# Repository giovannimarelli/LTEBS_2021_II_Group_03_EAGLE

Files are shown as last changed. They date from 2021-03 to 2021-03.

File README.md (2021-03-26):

# LTEBS_2021_II_Group_03_EAGLE
Laboratorio di Tecnologie Elettroniche e Biosensori S2021-II Group 03 EAGLE

In the Library folder, inside the Group_03_Library file we have inserted the two additional devices we were required to make and the microcontroller, for which we modified the footprint (setting line width of the silkscreen according to the manufacturer's specs); other devices referred to Sparkfun Library were not included, supposing to be in your possess. 
For what regards the TMUX device, we built the UQFN package, as specified by the description table inside the PDF, even if inside the provided schematic pins followed the 
TSSOP pattern. The same applies for the CY8CKIT059-TARGET: the table said to pick this, whereas inside the schematic the one used was the CY8CKIT059-TARGET_3: as before, we 
followed the table specs.

Inside the .brd file, Power Jack device looks like it exits the pcb: we intentionally placed it there folowing some examples online. 

All traces are of 10 mils, as you asked in the assignment document. However, due to the small dimension of the MUX, the design rules generated errors due to the clearance of the traces connecting the pads to the other pins. To overcome this problem, we decided to convert the width of all the traces connected to the MUX to 8 mils.

We added Silkscreen references for all SMD components, respecting manufacturer's rules of clearance and distance from the pads (8 mil from any exposed copper part).

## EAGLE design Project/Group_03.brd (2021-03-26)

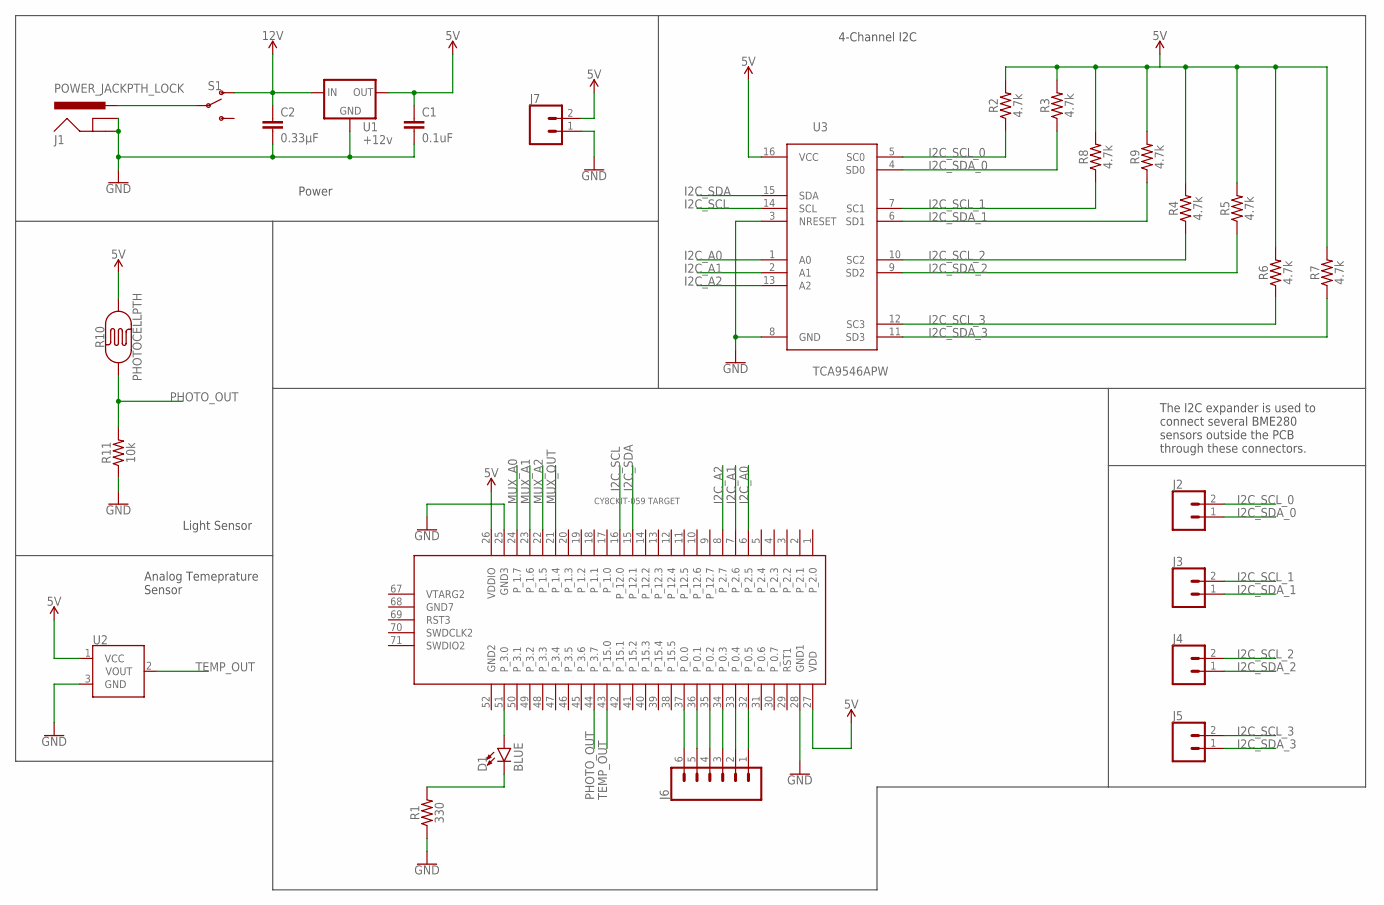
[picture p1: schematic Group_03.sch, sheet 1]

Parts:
C1: 0.1uF; CAP-PTH-SMALL-KIT
C2: 0.33µF; 0805
D1: BLUE; LED-1206
J1: POWER_JACKPTH_LOCK; POWER_JACK_PTH_LOCK
J2, J3, J4, J5, J7: CONN_02; 1X02
J6: CONN_06LOCK; 1X06_LOCK
R1: 330; AXIAL-0.3
R2, R3, R4, R5, R6, R7, R8, R9: 4.7k; 0603
R10: PHOTOCELLPTH; PHOTOCELL
R11: 10k; 0603
S1: SWITCH-SPDT-PTH-11.6X4.0MM; SWITCH_SPDT_PTH_11.6X4.0MM
U1: +12v; TO-252
U2: TMP36GT9; TO-92
U3: TCA9546APW; TSSOP16
U$1: CY8CKIT-059_TARGET

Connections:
5V: C1.1, J7.2, R2.2, R3.2, R4.2, R5.2, R6.2, R7.2, R8.2, R9.2, R10.2, U1.2 (OUT), U2.1 (VCC), U3.16 (VCC), U$1.26 (VDDIO), U$1.27 (VDD); also elsewhere on the board
12V: C2.1, S1.1 (O), U1.1 (IN)
GND: C1.2, C2.2, J1.GND, J1.GNDBREAK, J7.1, R1.P$1 (1), R11.1, U1.3 (GND), U2.3 (GND), U3.3 (NRESET), U3.8 (GND), U$1.25 (GND3), U$1.28 (GND1); also elsewhere on the board
I2C_A0: U3.1 (A0), U$1.6 (P_2.5)
I2C_A1: U3.2 (A1), U$1.7 (P_2.6)
I2C_A2: U3.13 (A2), U$1.8 (P_2.7)
I2C_SCL: U3.14 (SCL), U$1.16 (P_12.0)
I2C_SCL_0: J2.2, R2.1, U3.5 (SC0)
I2C_SCL_1: J3.2, R8.1, U3.7 (SC1)
I2C_SCL_2: J4.2, R4.1, U3.10 (SC2)
I2C_SCL_3: J5.2, R6.1, U3.12 (SC3)
I2C_SDA: U3.15 (SDA), U$1.15 (P_12.1)
I2C_SDA_0: J2.1, R3.1, U3.4 (SD0)
I2C_SDA_1: J3.1, R9.1, U3.6 (SD1)
I2C_SDA_2: J4.1, R5.1, U3.9 (SD2)
I2C_SDA_3: J5.1, R7.1, U3.11 (SD3)
MUX_A0: U$1.24 (P_1.7); also elsewhere on the board
MUX_A1: U$1.23 (P_1.6); also elsewhere on the board
MUX_A2: U$1.22 (P_1.5); also elsewhere on the board
MUX_OUT: U$1.21 (P_1.4); also elsewhere on the board
unnamed: J1.PWR, S1.2
unnamed: J6.1, U$1.32 (P_0.5)
unnamed: J6.2, U$1.33 (P_0.4)
unnamed: J6.3, U$1.34 (P_0.3)
unnamed: J6.4, U$1.35 (P_0.2)
unnamed: J6.5, U$1.36 (P_0.1)
unnamed: J6.6, U$1.37 (P_0.0)
unnamed: D1.A, U$1.51 (P_3.0)
unnamed: D1.C, R1.P$2 (2)
PHOTO_OUT: R10.1, R11.2, U$1.44 (P_3.7)
TEMP_OUT: U2.2 (VOUT), U$1.43 (P_15.0)

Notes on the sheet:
The I2C expander is used to connect several BME280 sensors outside the PCB through these connectors.
Analog Temeprature Sensor
Light Sensor
Power
4-Channel I2C

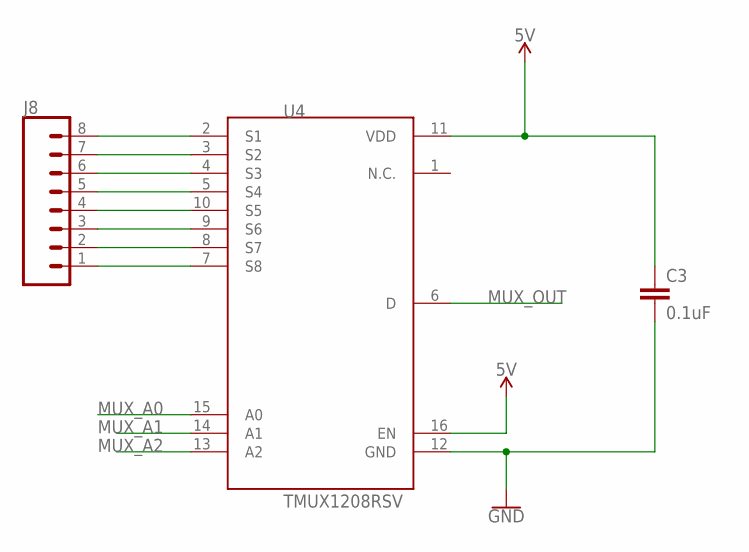
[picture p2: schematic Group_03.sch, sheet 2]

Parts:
C3: 0.1uF; CAP-PTH-SMALL-KIT
J8: CONN_08LOCK; 1X08_LOCK
U4: TMUX1208RSV; QFN16

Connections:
5V: C3.1, U4.11 (VDD), U4.16 (EN); also elsewhere on the board
GND: C3.2, U4.12 (GND); also elsewhere on the board
MUX_A0: U4.15 (A0); also elsewhere on the board
MUX_A1: U4.14 (A1); also elsewhere on the board
MUX_A2: U4.13 (A2); also elsewhere on the board
MUX_OUT: U4.6 (D); also elsewhere on the board
unnamed: J8.8, U4.2 (S1)
unnamed: J8.7, U4.3 (S2)
unnamed: J8.6, U4.4 (S3)
unnamed: J8.5, U4.5 (S4)
unnamed: J8.4, U4.10 (S5)
unnamed: J8.3, U4.9 (S6)
unnamed: J8.2, U4.8 (S7)
unnamed: J8.1, U4.7 (S8)

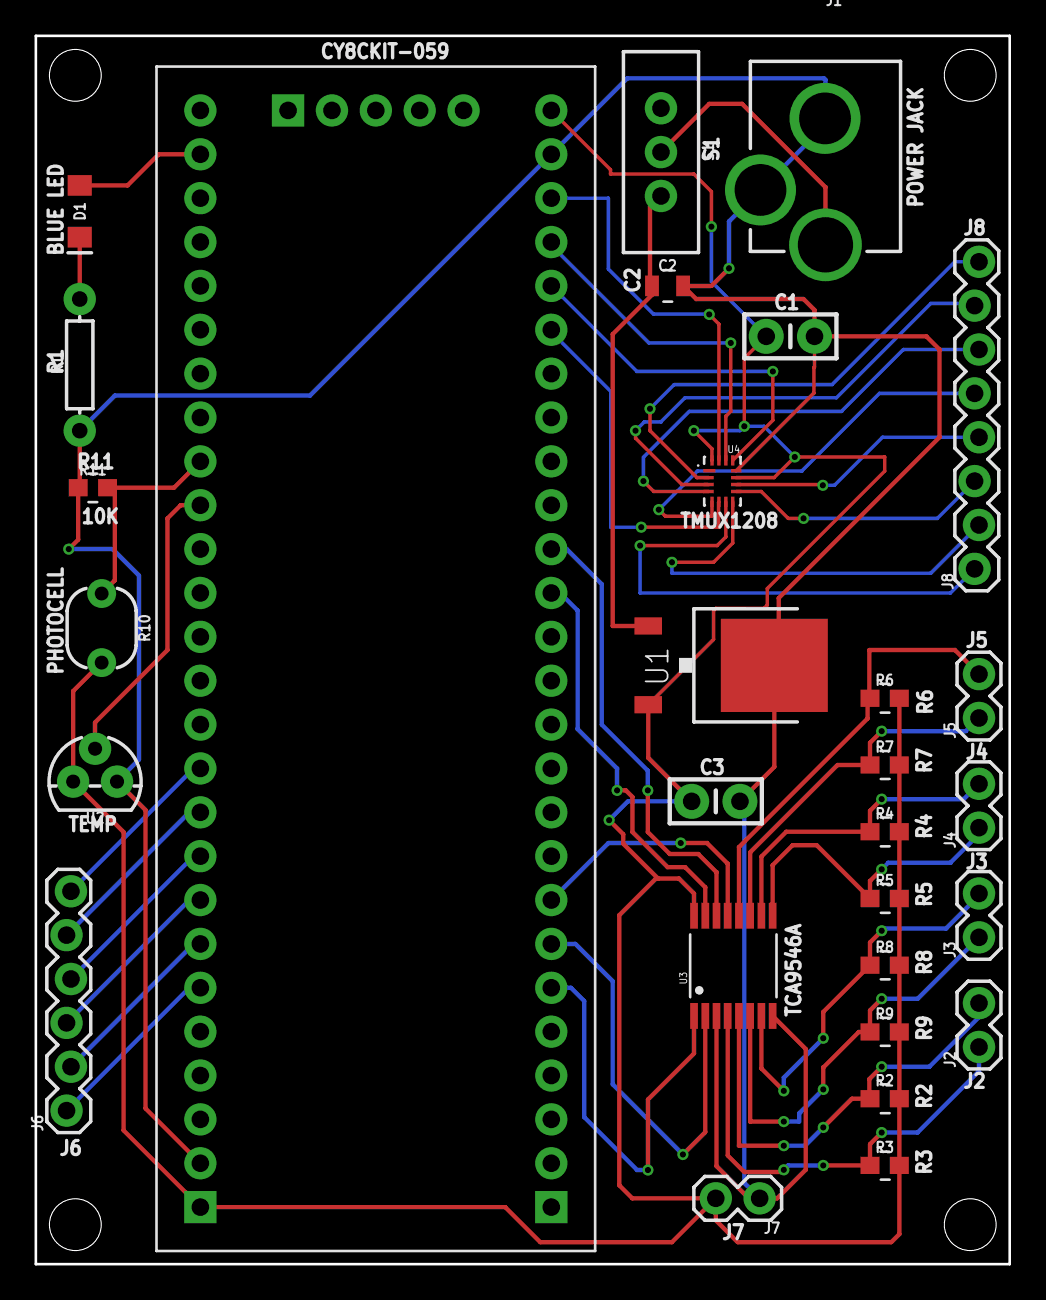
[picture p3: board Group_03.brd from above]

Board: 2 copper layers, 56.4 x 71.1 mm, 29 parts (0 on the bottom side), 39 nets.

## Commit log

2021-03-18 Add .gitignore file
    [Group_03.sch]
2021-03-18 Remove folder
    [Group_03.sch]
2021-03-18 Re-add folder to apply .gitignore
    [Group_03.sch]
2021-03-18 Folder con schematico di prova
    [Prova01.sch]
2021-03-18 Aggiunta del file PCB (.brd)
    [Prova01.brd]
2021-03-19 Remove folder di prova
    [Prova01.brd, Prova01.sch]
2021-03-19 Correction of pin/pad connection
2021-03-19 Start of the schematic, PowerJack, Conn2
    [Group_03.sch]
2021-03-19 Add light and temperature sensors
    [Group_03.sch]
2021-03-19 Layout editing
    [Group_03.sch]
2021-03-20 Add 4-Channel I2C
    [Group_03.sch]
2021-03-20 Add last comments + layout editing
    [Group_03.sch]
2021-03-20 Add of TMUX and CY8CKIT
    [Group_03.sch]
2021-03-20 Generation of empty board
    [Group_03.brd]
2021-03-20 Start of PCB placing
    [Group_03.brd]
2021-03-20 Placement on board completed
    [Group_03.brd]
2021-03-20 Move names
    [Group_03.brd]
2021-03-20 Moved CY8CKIT
    [Group_03.brd]
2021-03-20 First board layout attempt
    [Group_03.brd]
2021-03-20 Parts placement (size 73.66x71.12)
    [Group_03.brd]
2021-03-20 Blue vias version (71.12x60.96)
    [Group_03.brd]
2021-03-21 Completed wiring, and design rules update
    [Group_03.brd, Group_03.sch]
2021-03-21 Silkscreen names
    [Group_03.brd]
2021-03-21 Copper pour both layers
    [Group_03.brd]
2021-03-22 Clearance errors fixed
    [Group_03.brd]
2021-03-22 Change silkscreen line width in Library for MUX, TCA and CY8
    [Group_03.brd, Group_03.sch]
2021-03-22 Last modifications to schematic, board and check rules
    [Group_03.brd, Group_03.sch]
2021-03-26 Silscreen SMD components
    [Group_03.brd]
2021-03-26 Silkscreen adjustment for custom components
    [Group_03.brd, Group_03.sch]
2021-03-26 Polygon isolation correction
    [Group_03.brd]
2021-03-26 Last modifications
    [Group_03.brd]
2021-03-26 Final version
    [Group_03.brd]

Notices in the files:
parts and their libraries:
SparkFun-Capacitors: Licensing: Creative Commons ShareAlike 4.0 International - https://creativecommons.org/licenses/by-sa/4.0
